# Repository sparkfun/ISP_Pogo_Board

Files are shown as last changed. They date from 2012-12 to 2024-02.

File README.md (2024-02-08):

ISP Pogo Adapter
================

ISP Pogo Adapter (https://www.sparkfun.com/products/23451)

_[ISP Pogo Adapter (KIT-23451)](https://www.sparkfun.com/products/23451)_

This is a simple adapter board that allows you to adapt pogo pins to an 6-pin ISP header. 

Repository Contents
-------------------
* **/Hardware** - All Eagle design files (.brd, .sch)

Documentation
--------------

* **[Assembly Video](https://youtu.be/aZCB-krwbAk?si=Pytt60uzcoHceXtl)** - Tutorial video showing how to assembly the ISP Pogo Adapter.
* **[PogoBeds: SparkFun Production and Testing](https://www.sparkfun.com/tutorials/138)** - How We Use Pogo Boards
* **[Pocket AVR Programmer Hookup Guide](https://learn.sparkfun.com/tutorials/pocket-avr-programmer-hookup-guide)** - Basic hookup guide for the Pocket AVR Programmer. 
* **[Installing an Arduino Bootloader](https://learn.sparkfun.com/tutorials/installing-an-arduino-bootloader)**  - Example of installing an Arduino bootloader on an Atmega328P-based microcontrollers (i.e. Arduino Uno and RedBoard Programmed with Arduino) through the Arduino IDE and command line using avrdude.

Product Versions
----------------
* [KIT-23451](https://www.sparkfun.com/products/23451) - v1.0, without the polarized jumper wire cable
* [KIT-11591](https://www.sparkfun.com/products/11591) - v1.0

Version History
---------------
* v1.0 - Initial Release

License Information
-------------------
The hardware is released under [Creative Commons Share-alike 3.0](http://creativecommons.org/licenses/by-sa/3.0/).

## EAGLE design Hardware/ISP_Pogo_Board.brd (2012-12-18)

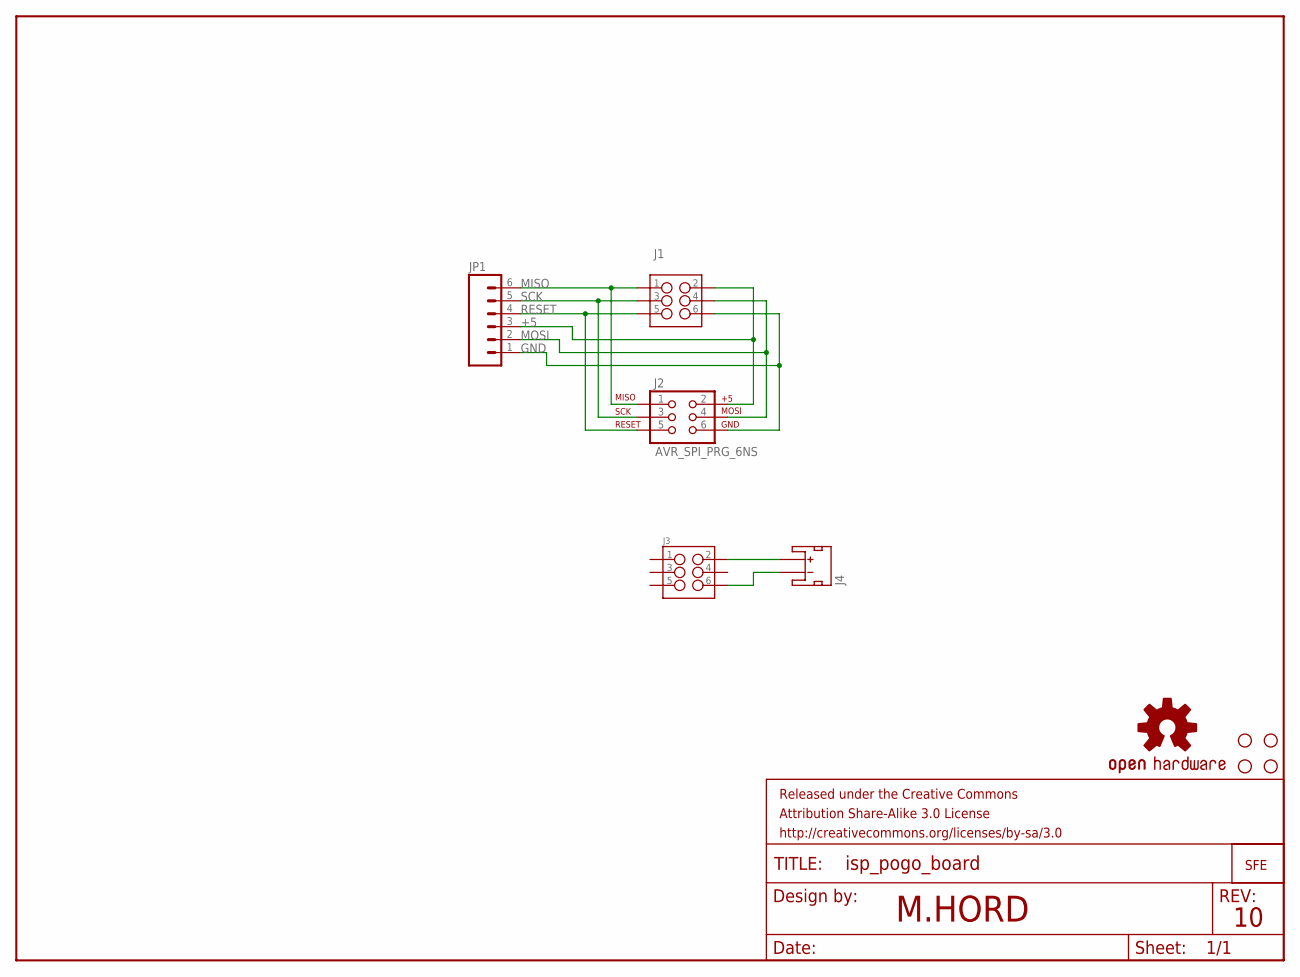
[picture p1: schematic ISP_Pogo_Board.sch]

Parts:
FRAME1: FRAME-LETTER; CREATIVE_COMMONS
J1, J3: M03X2POGO_PINS; 2X3_POGO
J2: AVR_SPI_PRG_6NS; 2X3-NS
J4: JST_2MM_MALE; JST-2-SMD
JP1: M06POLAR; MOLEX-1X6
JP2, JP3, JP4, JP5: STAND-OFF
JP6: LOGO-SFENW2; SFE-NEW-WEB
U$1: OSHW-LOGOS; OSHW-LOGO-S

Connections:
+5: J1.P$2 (2), J2.2, JP1.3
GND: J1.P$6 (6), J2.6, JP1.1
MISO: J1.P$1 (1), J2.1, JP1.6
MOSI: J1.P$4 (4), J2.4, JP1.2
unnamed: J3.P$2 (2), J4.2 (+)
unnamed: J3.P$6 (6), J4.1 (-)
RESET: J1.P$5 (5), J2.5, JP1.4
SCK: J1.P$3 (3), J2.3, JP1.5

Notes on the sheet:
M.HORD

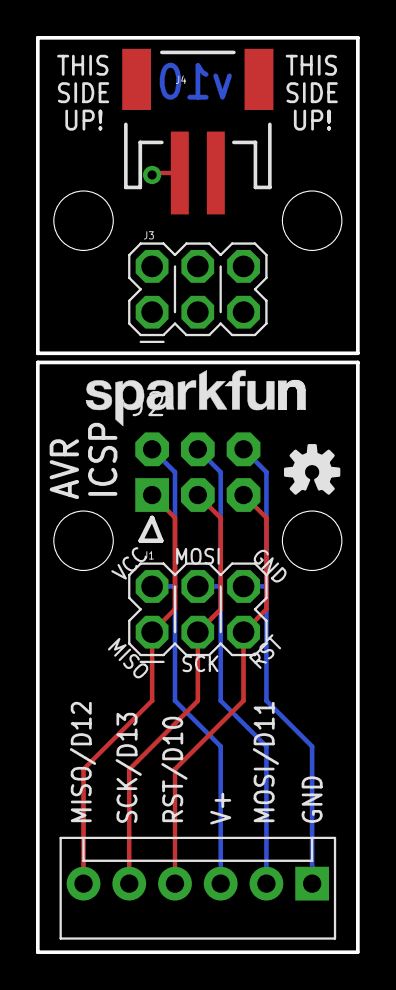
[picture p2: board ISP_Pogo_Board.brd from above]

Board: 2 copper layers, 17.8 x 50.8 mm, 12 parts (0 on the bottom side), 8 nets.

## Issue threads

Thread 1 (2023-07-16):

Pogo Pin Size

kontakt, 2023-07-16:
What size pogo pins are used with this design?

bboyho, 2024-02-02:
Hi!

Sorry, I just noticed this question when updating the repo.  These use the pointed tip pogo pins and they should be linked on the product page. If you have not already, make sure to check out the [product page for the pointed tip pogo pin](https://www.sparkfun.com/products/9174) for the dimensional drawing and measurements. According to the product page:

> * Length: 1.3" (33mm)
> * Travel: 1/4" (6.5mm)
> * Head size 0.05" (1.3mm)

These can be used with standard 0.1"-spaced PTHs.

Closed 2024-02-02.

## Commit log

2012-12-11 Initial commit- these are version 02 hardware files, which increase the size of the holes for the pogo pins (they were too tight on the initial proto run), adds "This Side Up" text to the bottom boar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
    [ISP_Pogo_Board.brd, ISP_Pogo_Board.sch]
2012-12-18 Changed for v10: Made planes not overlap vscore region Increased annular ring on pogo pin pads
    [ISP_Pogo_Board.brd, ISP_Pogo_Board.sch]

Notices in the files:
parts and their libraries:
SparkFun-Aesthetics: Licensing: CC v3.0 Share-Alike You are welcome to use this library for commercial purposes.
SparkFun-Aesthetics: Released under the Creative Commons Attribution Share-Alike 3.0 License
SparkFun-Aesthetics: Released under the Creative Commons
